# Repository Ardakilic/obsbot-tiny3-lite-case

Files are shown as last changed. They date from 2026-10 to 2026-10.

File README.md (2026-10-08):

# OBSBOT Tiny 3 Lite carry case

A 3D-printable two-part carry case for the **OBSBOT Tiny 3 Lite** webcam — there was
none. The camera lies flat in a shallow tray under a deep lid, so you pick it up by
the body and never by the gimbal head. Four closure variants (friction, snap detent,
two magnetic), everything generated from one parametric Python script, built
entirely inside Docker.

**Browse the interactive 3D previews and download STLs at
[ardakilic.github.io/obsbot-tiny3-lite-case](https://ardakilic.github.io/obsbot-tiny3-lite-case/).**

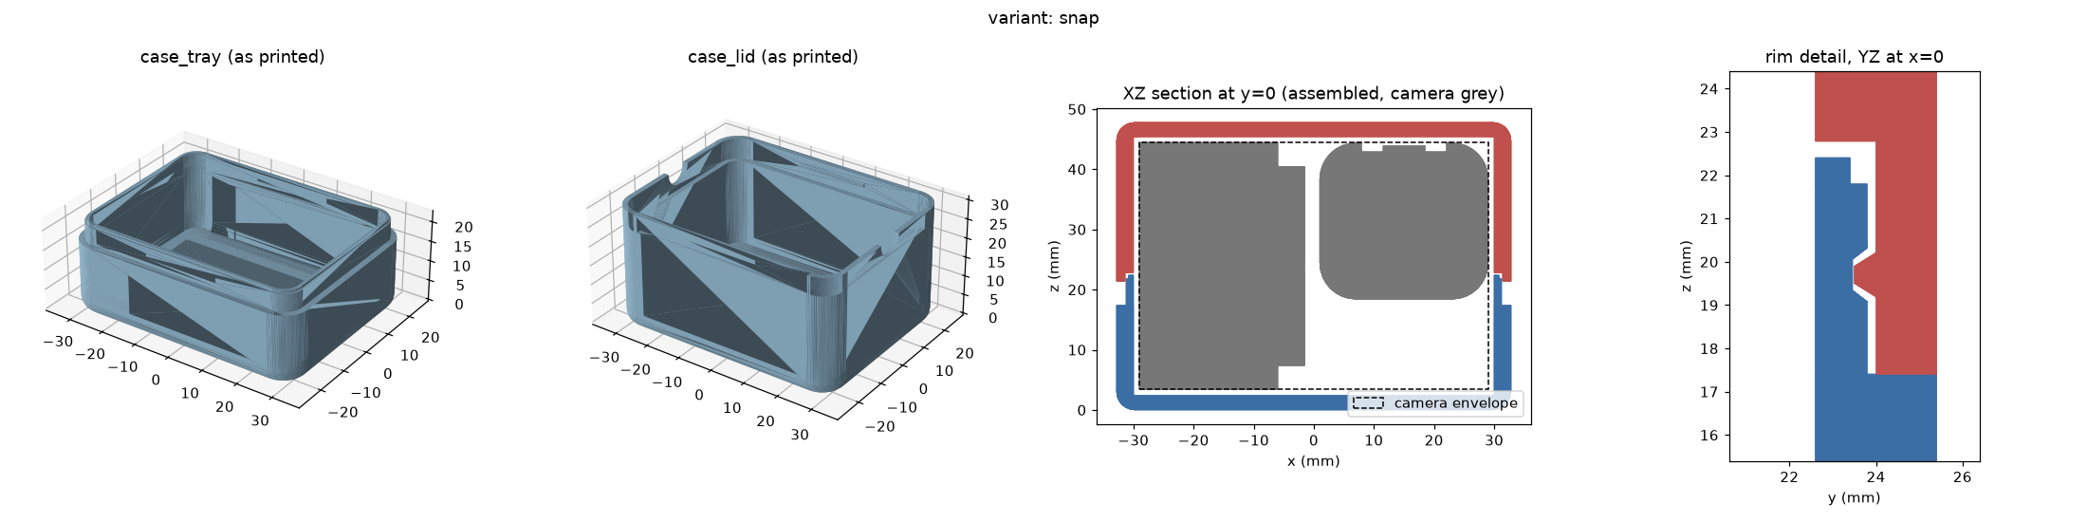
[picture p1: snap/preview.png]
Snap variant: tray, lid, section with the camera, rim detail

*Snap variant — tray and lid as printed, assembled section with the (approximate)
camera model, and the rim detail showing the detent seated in the tongue.*

## The four variants

| | Friction fit — [`friction/`](friction/) | Snap detent — [`snap/`](snap/) | Magnetic — [`magnet/`](magnet/) | Magnetic ×4 — [`magnet4/`](magnet4/) |
|---|---|---|---|---|
| Closure | Slip-fit tongue and groove, 0.2 mm clearance | Same tongue and groove plus a 20 mm ridge inside each long lid wall that clicks into a recess in the tongue | Glide-fit tongue and groove (0.35 mm), held by 2 magnet pairs in lobes mid-way along the long walls | Same, 4 pairs at ±15 mm |
| Stays closed in a bag? | Not guaranteed — friction only | Yes — the lid wall must flex over the detent | Yes — ≈ 12–15 N to pull straight off | Yes — ≈ 25–30 N; peel one end first |
| Hardware | none | none | 4 × Ø6 × 3 mm disc magnets, glue | 8 × Ø6 × 3 mm disc magnets, glue |
| Walls / tongue | 2.4 / 1.0 mm | 2.8 / 1.2 mm (room for the recess) | 2.4 / 1.0 mm + lobes | 2.4 / 1.0 mm + lobes |
| Outer size | 64.8 × 50.0 × 47.8 mm | 65.6 × 50.8 × 47.8 mm | 64.8 × 65.9 × 47.8 mm | 64.8 × 65.9 × 47.8 mm |
| Filament (PETG) | ≈ 44 g | ≈ 50 g | ≈ 53 g | ≈ 62 g |
| Preview | [friction](https://ardakilic.github.io/obsbot-tiny3-lite-case/friction/preview.html) | [snap](https://ardakilic.github.io/obsbot-tiny3-lite-case/snap/preview.html) | [magnet](https://ardakilic.github.io/obsbot-tiny3-lite-case/magnet/preview.html) | [magnet4](https://ardakilic.github.io/obsbot-tiny3-lite-case/magnet4/preview.html) |

The magnetic variants follow the magnet-skirt design of [filtarr](https://github.com/Ardakilic/filtarr):
blind pockets Ø6.4 × 3.2 mm for Ø6 × 3 mm discs, so each magnet sits 0.2 mm recessed and
facing pairs never touch (a controlled snap instead of a hard clack). The pockets open
toward the print top on both parts, so no bridging. Filtarr's flat-lid and pedestal
designs don't transfer: they need a deep tray, which is exactly what makes a camera
hard to grab, so this case keeps its shallow tray and puts the magnets at the split.

Each folder holds `tiny3lite_case_tray.stl`, `tiny3lite_case_lid.stl`, a render sheet
`preview.png`, the interactive `preview.html`, and `tiny3lite_camera.stl` — an
approximate camera model used only for visualisation and the fit checks (don't print it).

## How it is designed

- **Camera lying flat, lens up.** The cavity is 60 × 45.2 × 43 mm: the 60 × 45.2
  pocket is taken from the community
  [Gridfinity organizer](https://www.printables.com/model/1620707-obsbot-tiny-3-lite-webcam-gridfinity-organizer)
  for this camera, whose author test-fitted a real unit (1 mm clearance per end,
  2.1 mm per side); 1 mm above and below the camera's 41 mm.
- **Shallow tray, deep lid.** The tray holds only the bottom 15 mm of the camera;
  26 mm of the body stands proud when the lid is off, so it lifts out by the base.
  No finger scoops are needed, so the closed case has no holes. The weight rests on
  the base; the gimbal head floats with clearance.
- **Tongue and groove** with a lead-in on the tongue tip, two thumb notches on the
  lid's end faces, two crush ribs under the camera base against rattle, rounded
  edges and corners all round.
- **Snap detent** (snap variant): a trapezoidal ridge on the lid's groove wall with
  ~45° ramps both ways, seated in a matching recess in the tongue; the full-thickness
  tongue band above the recess retains the lid.
- **Magnet lobes** (magnet variants): the walls are too thin for a 6.4 mm pocket, so
  each magnet pair lives in a full-height 10 mm lobe on the outside of the long wall,
  blended into the wall with 5 mm fillets (a morphological closing of the outline,
  like filtarr). Pocket centres are 0.8 mm of skin outside the lid's groove wall.
- The outer shell is the plan outline with every edge rounded by 3 mm (a Minkowski
  sum with a sphere), so lobes and corners get the same soft edges.
- Both parts print open side up with no supports.

## Printing

0.2 mm layers, 3 or more perimeters, ~15 % infill, PETG (preferred, the snap flexes
better) or PLA, no supports, both parts as exported (open side up, flat on the bed).

Drop the camera in with the base toward the ribs (the −x end in the viewer), lens
up. Fit tuning after a test print — change parameters, never the geometry:

| Symptom | Fix |
|---|---|
| Lid too tight / too loose (friction) | `make VARIANTS=friction FIT=0.25` / `FIT=0.15` |
| Snap too hard to close | lower in 0.05 steps: `make VARIANTS=snap SNAP=0.25`, or shorten `SNAP_L` |
| Snap pops open | raise `SNAP` |
| Camera rattles / binds | `CLEAR_W` or `RIB` |
| Magnets won't go in / sit proud | `POCKET_D=6.5` / `POCKET_DEPTH=3.4` |

### Magnets (magnet and magnet4)

Ø6 × 3 mm neodymium discs (N35 is plenty). Get the polarity right on the first try:

1. Glue the tray-side magnets into the **tray** pockets (a drop of superglue or epoxy
   per pocket, press flush). Orientation doesn't matter yet.
2. Once cured, drop the remaining magnets **onto the glued ones**; they snap on in the
   correct orientation by themselves.
3. Put a drop of glue in each **lid** pocket, align the lid and press it fully closed.
   The loose magnets seat into the lid pockets with the right polarity. Let it cure
   closed. Gel superglue or 5-minute epoxy is cleaner than thin superglue, whose fumes
   can leave a white residue.

## FAQ

**Will the magnets harm the webcam in long-term storage (magnet and magnet4)?**
No. In both variants the magnets sit outside the lid's groove wall, so a magnet's edge
is about 4 mm from the camera's skin (2 mm of plastic plus the 2 mm side clearance)
and about 11 mm from the pan motor in the turntable; the 4-pair variant adds magnets
beside the base and the tilt axle at the same distances. A Ø6 × 3 mm N35 disc gives
roughly 400 mT at its face, but the field falls off steeply and the camera lies beside
the magnets, not on their axis: about 15–25 mT at the camera's surface and under 5 mT
at the motors, fridge-magnet territory. Nothing in the camera can be hurt by that:
the gimbal's brushless motors run on their own neodymium magnets (≈1 T, and it takes a
field of that order to demagnetize them), the angle encoders only read wrong while a
field is present and the camera is off in the case, and the CMOS sensor, flash memory,
MEMS microphones and focus actuator are not magnetic media. OBSBOT itself seats a
stronger magnet permanently in the base of the regular Tiny 3 for its mount
([Digital Camera World](https://www.digitalcameraworld.com/tech/webcams/obsbot-tiny-3-review)),
and makers of magnetic camera accessories report no effects on cameras, phones or
laptops ([MagMod](https://support.magnetmod.com/en-US/will-magnets-damage-my-camera-gear-or-electronic-equipment-232239)).
The caveat is about other things, not the camera: the lobes carry tens of mT at their
surface, enough to wipe a magnetic-stripe hotel card, so keep the closed case away from
cards, mechanical watches and medical implants.

## Building it yourself

Requires only Docker and `make`; nothing is installed on the host.

```sh
make                          # STLs + geometry checks + previews + index.html, all four variants
make stl                      # <variant>/tiny3lite_case_tray.stl, _case_lid.stl, _camera.stl
make check                    # self-checks: watertight, fit, no interference, detent engages
make preview                  # <variant>/preview.png + preview.html
make VARIANTS=snap SNAP=0.25  # one variant with overrides (any parameter below)
make clean
open snap/preview.html        # viewer: Tray / Lid / Camera / X-ray / Cut toggles, Explode slider,
                              # "As printed" layout; needs internet for the three.js CDN
```

`make check` builds every part in memory and asserts: watertight meshes, tray and lid
do not interfere when closed, a sharp 58 × 41 × 41 block *and* the camera model clear
the tray (ribs included) and the lid, assembled size equals the spec, the tongue sits
fully inside the groove, and — the closure test — lifting the lid 1 mm interferes by
≈7 mm³ on the snap variant and by exactly nothing on the others. Magnet variants also
prove every pocket is blind, coaxial across the split and surrounded by at least
0.8 mm of material, and that the magnets sit recessed.

### Parameters (mm, environment variables)

| Name | Default | Meaning |
|---|---|---|
| CAM_W, CAM_D, CAM_H | 41, 41, 58 | Camera bounding box, standing (width, depth, height) |
| CLEAR_L | 1.0 | Clearance per end along the camera's 58 mm length (cavity 60) |
| CLEAR_W | 2.1 | Clearance per side across the 41 mm width (cavity 45.2) |
| CLEAR_H | 1.0 | Clearance above and below the lying camera (cavity 43 tall) |
| WALL | 2.4 (snap 2.8) | Side wall thickness |
| FLOOR | 2.4 | Floor of the tray / ceiling of the lid |
| R_IN | 4 | Cavity vertical corner radius; outer radius = R_IN + WALL |
| R_EDGE | 3 | Rounding of the outer top and bottom edges |
| TRAY | 15 | Cavity height held by the tray; the lid holds the rest |
| LIP_H, LIP_T | 5, 1.0 (snap 1.2) | Tongue height and thickness (0.6 mm lead-in at the tip) |
| FIT | 0.2 (magnet 0.35) | Radial clearance between tongue and groove |
| NOTCH_R | 4 | Thumb notch radius on the lid's end faces |
| RIB | 0.6 | Height of the two anti-rattle ribs (0 disables) |
| SNAP | 0 (snap 0.3) | Detent interference depth; 0 = no detent |
| SNAP_L | 20 | Detent length along each long wall |
| MAG | 0 (magnet 2, magnet4 4) | Magnet pairs: 2 = one per long wall at x = 0, 4 = two per wall at ±15 |
| MAG_D, MAG_T | 6, 3 | Magnet disc diameter and thickness |
| POCKET_D, POCKET_DEPTH | 6.4, 3.2 | Pocket diameter and depth (0.2 mm recess per side) |
| LOBE_R, BLEND | 5.0, 5.0 | Lobe radius around each pocket, fillet radius blending it into the wall |

## Camera dimensions (researched)

**41 × 41 × 58 mm (W × D × H), 73 g.** OBSBOT's own
[comparison table](https://www.obsbot.com/comparison?from=tiny-3-series) and every
retailer sheet agree ([JB Hi-Fi](https://www.jbhifi.com.au/products/obsbot-tiny-3-lite-ai-powered-ptz-4k-webcam)
labels the axes W × H × D = 41 × 58 × 41; [Thomann](https://www.thomann.de/be/obsbot_tiny_3_lite.htm);
[Micro Center](https://microcenter.com/quickView/705519/obsbot-tiny-3-lite-ai-powered-4k-ptz-webcam)).
The regular Tiny 3 is 37 × 37 × 49 mm / 63 g with a detachable magnetic mount, so its
files don't apply.

Shape (official photos and the user manual): square base with rounded corners, a
fold-flat stand hinged under the rear of the base, UNC 1/4-20 socket in the bottom,
USB-C on the back, round pan turntable with LED ring, an L-arm carrying the rounded
lens head with a red ring; the lens tilts down for sleep. Folded, it is the
41 × 41 × 58 box the case is designed around. The camera model in the previews is
eyeballed from those photos within that box.

## Project layout

```
case.py            the generator: parameters, camera model, case geometry, checks, previews, index page
Makefile           every target is a docker run; Dockerfile pins the image and wheels
friction/ snap/ magnet/ magnet4/   generated outputs (committed, so GitHub Pages and the STL links just work)
index.html         generated Pages landing page
CLAUDE.md          design notes and rules for AI agents working on the repo (AGENTS.md points to it)
```

## License

Code: [MIT](LICENSE). Models and images: [CC BY 4.0](LICENSE-MODELS). The Gridfinity
organizer used as the fit reference is not included; see its
[Printables page](https://www.printables.com/model/1620707-obsbot-tiny-3-lite-webcam-gridfinity-organizer).
OBSBOT and Tiny 3 Lite are trademarks of their owner; this is an independent accessory.

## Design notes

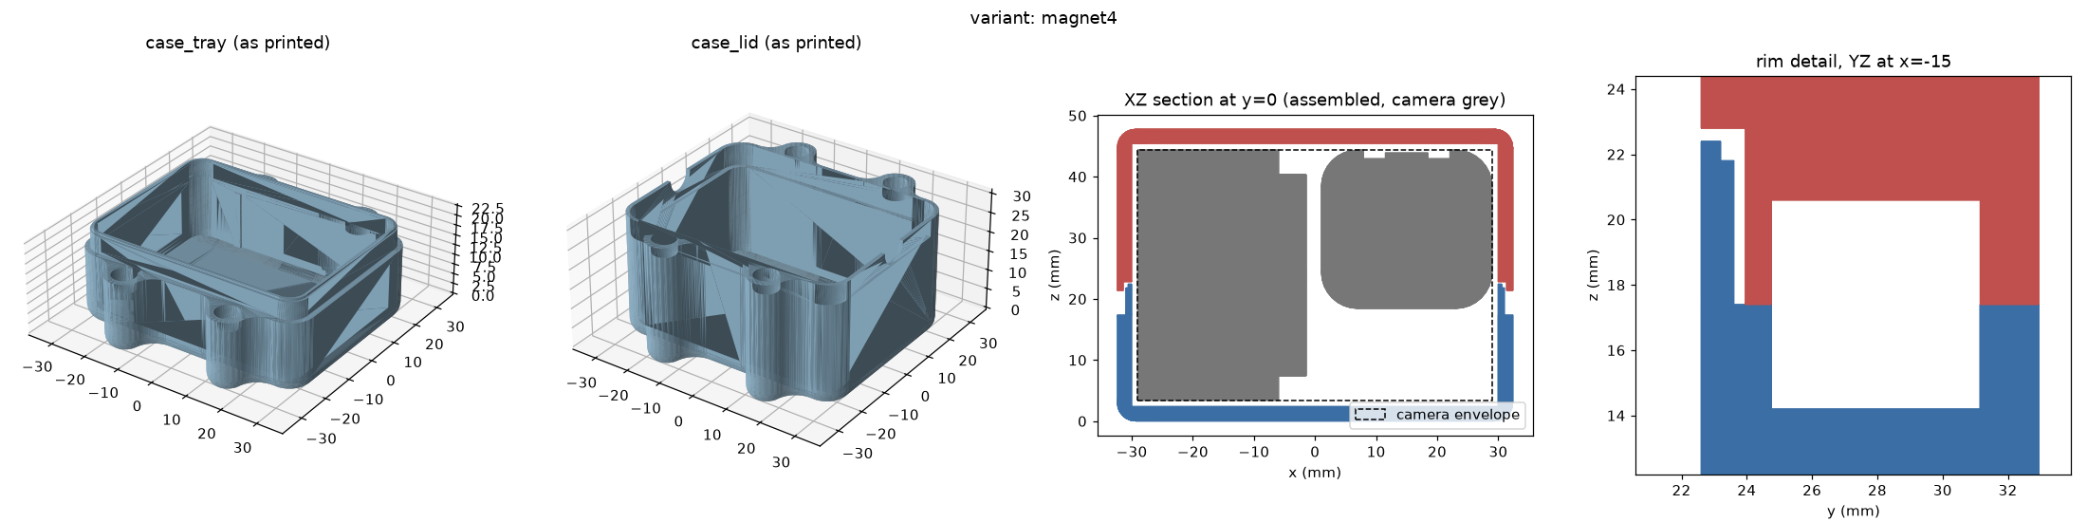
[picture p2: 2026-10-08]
magnet4/preview.png

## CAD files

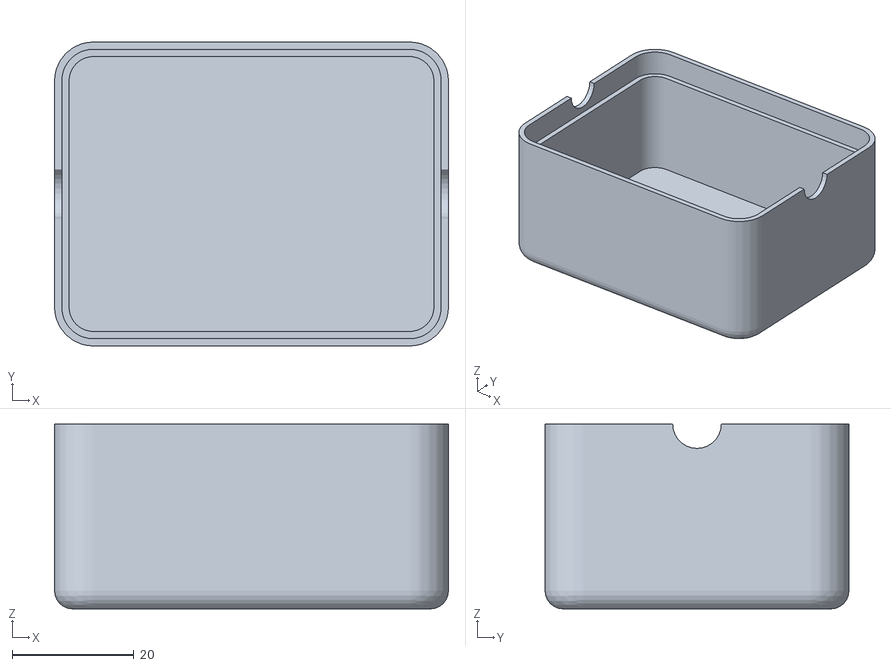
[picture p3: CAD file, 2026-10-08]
friction/tiny3lite_case_lid.stl
64.8 x 50.0 x 30.4

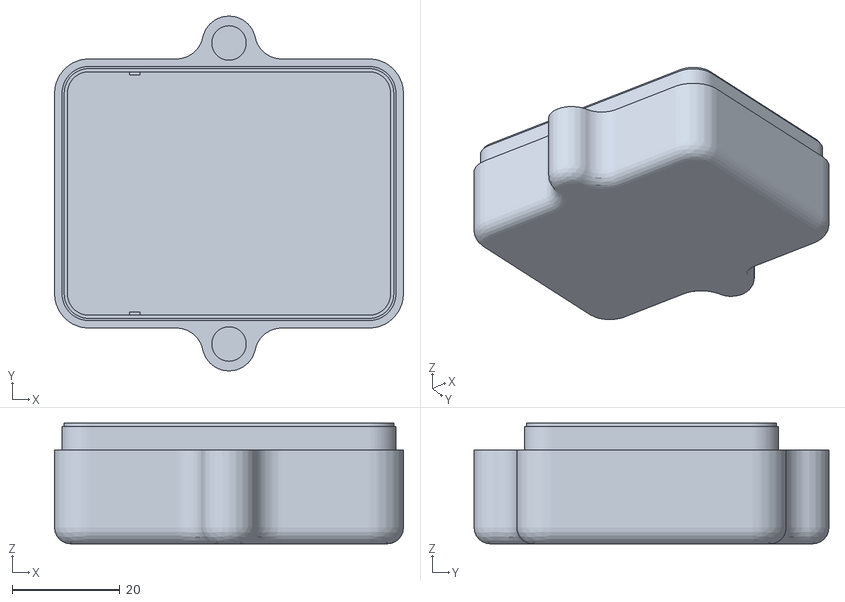
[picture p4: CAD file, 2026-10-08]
magnet/tiny3lite_case_tray.stl
64.8 x 65.9 x 22.4

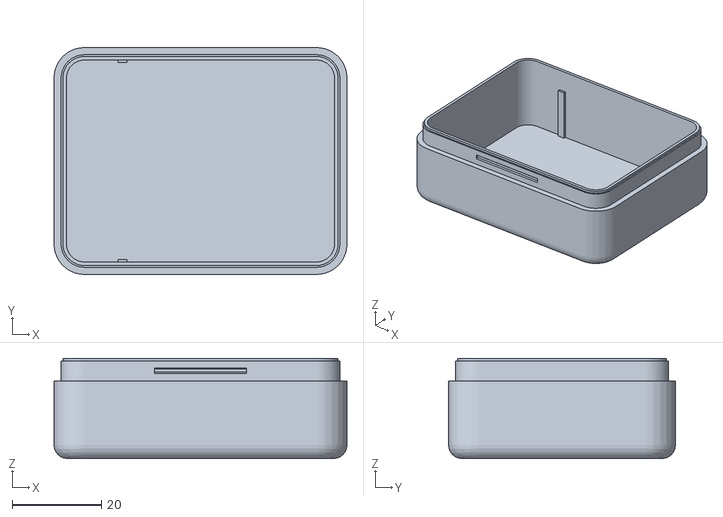
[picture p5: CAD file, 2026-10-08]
snap/tiny3lite_case_tray.stl
65.6 x 50.8 x 22.4

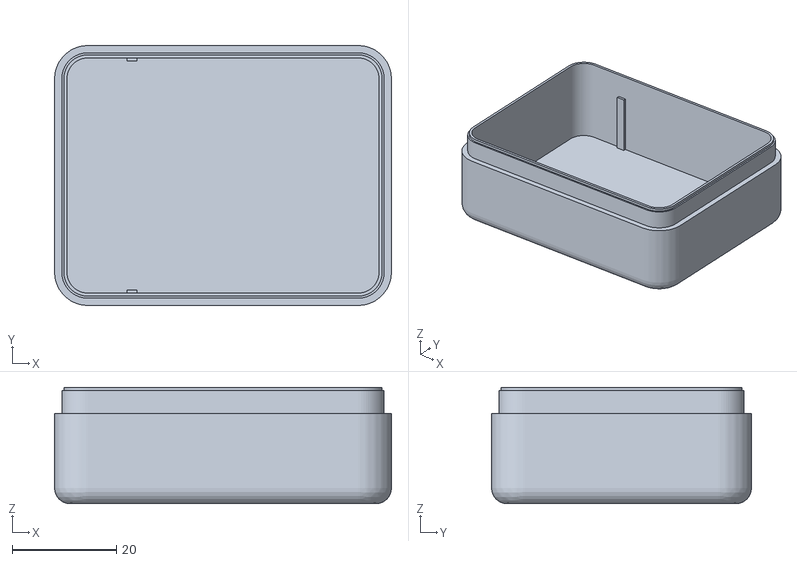
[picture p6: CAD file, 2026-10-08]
friction/tiny3lite_case_tray.stl
64.8 x 50.0 x 22.4

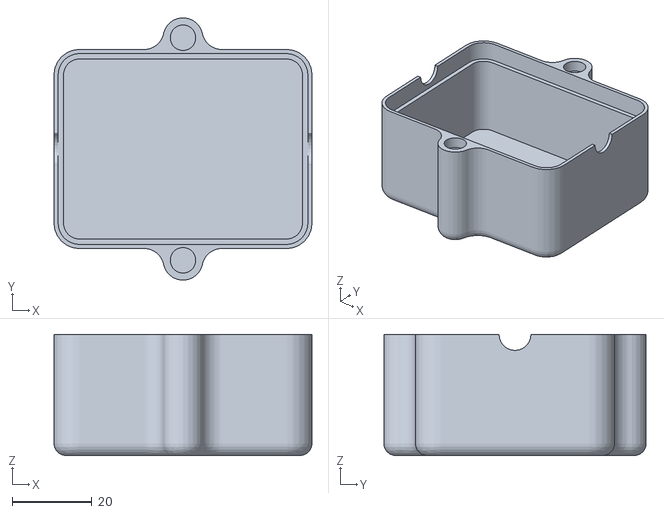
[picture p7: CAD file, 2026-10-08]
magnet/tiny3lite_case_lid.stl
64.8 x 65.9 x 30.4

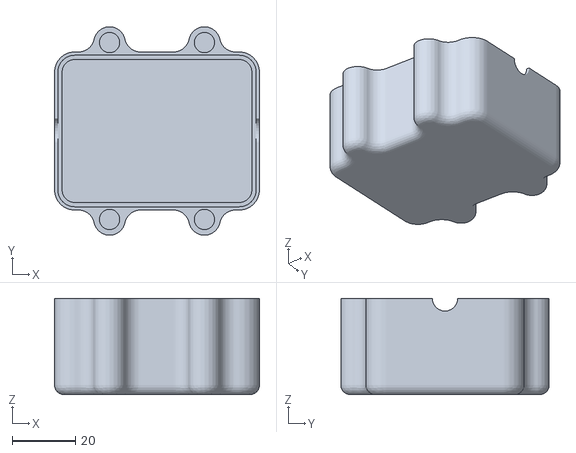
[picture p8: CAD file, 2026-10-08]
magnet4/tiny3lite_case_lid.stl
64.8 x 65.9 x 30.4

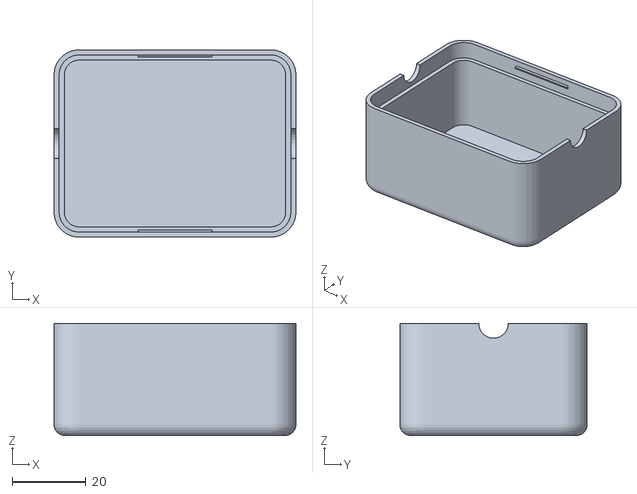
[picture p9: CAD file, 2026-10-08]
snap/tiny3lite_case_lid.stl
65.6 x 50.8 x 30.4

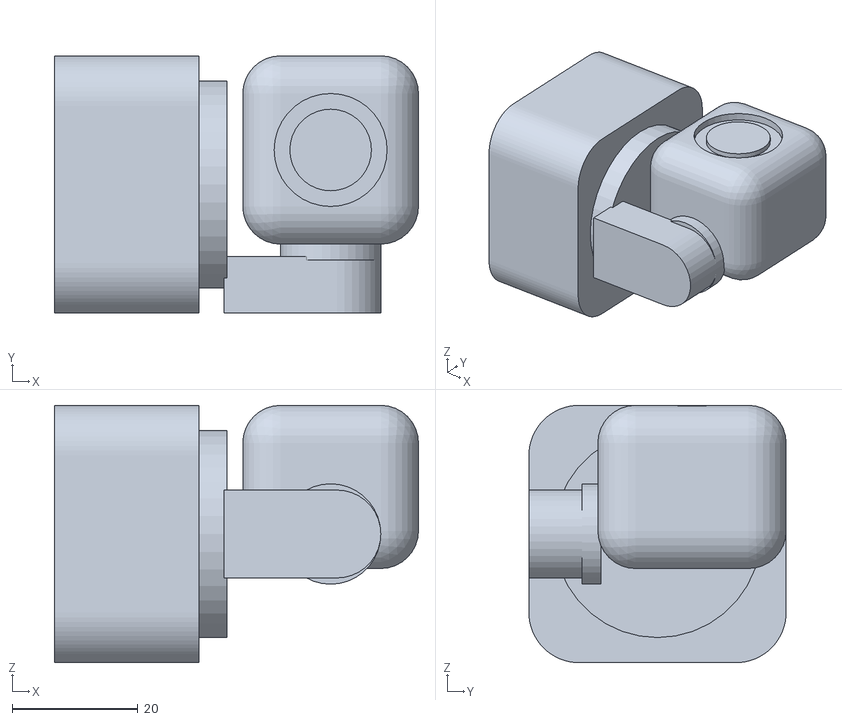
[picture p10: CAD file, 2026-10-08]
magnet/tiny3lite_camera.stl
58.0 x 41.0 x 41.0

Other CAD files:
magnet4/tiny3lite_case_tray.stl

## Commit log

2026-10-08 Parametric 3D-printed carry case for the OBSBOT Tiny 3 Lite
    Camera lies flat in a shallow tray under a deep lid (tongue and groove,
    thumb notches, crush ribs). Two variants generated from case.py: friction
    fit and snap detent. Geometry self-checks, matplotlib render sheets,
    self-contained three.js previews and the Pages landing page are all
    produced by `make`, entirely inside Docker.
    [tiny3lite_camera.stl, tiny3lite_case_lid.stl, tiny3lite_case_tray.stl]
2026-10-08 Add magnetic variants (2 and 4 pairs) modelled on filtarr's magnet-skirt design
    magnet / magnet4: glide-fit tongue and groove (FIT 0.35) held shut by Ø6×3 mm
    disc magnets in Ø6.4×3.2 blind pockets, coaxial across the split plane, each
    inside a full-height lobe blended into the long wall. The outer shell is now
    a Minkowski sum of the plan outline and a sphere so lobes and corners share
    the same 3 mm edge rounding (friction/snap re-exported, geometry unchanged).
    Checks prove the pockets are blind, enclosed by >= 0.8 mm and recessed; the
    viewer shows the magnets and the index lists the hardware.
    [tiny3lite_camera.stl, tiny3lite_case_lid.stl, tiny3lite_case_tray.stl]
2026-10-08 README: FAQ on magnet safety for the magnet and magnet4 variants
    Distances from the pockets to the camera skin and motors, the field falloff
    of a 6x3 mm N35 disc, why motors/encoders/sensor/flash are unaffected, and
    the mag-stripe card caveat. Numbers recorded in CLAUDE.md for later edits.
